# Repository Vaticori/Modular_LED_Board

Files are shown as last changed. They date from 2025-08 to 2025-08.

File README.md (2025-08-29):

# Modular LED Board TMR
Modular PCB to supply power to and control LED strips, providing input for both 5V and 12V. For the Mars Rover of the Toronto Metropolitan Robotics Team

# [View Interactive 3D Model of my PCB!](https://skfb.ly/pACWx)
 
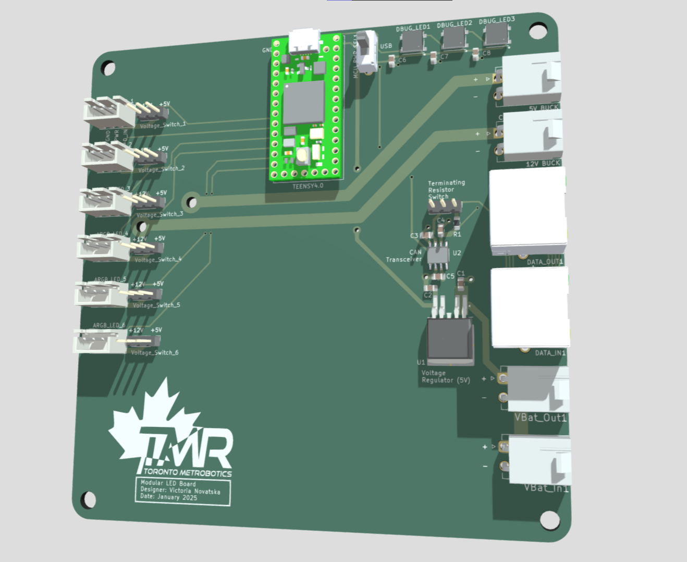
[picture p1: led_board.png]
Led Board


## Schematic 
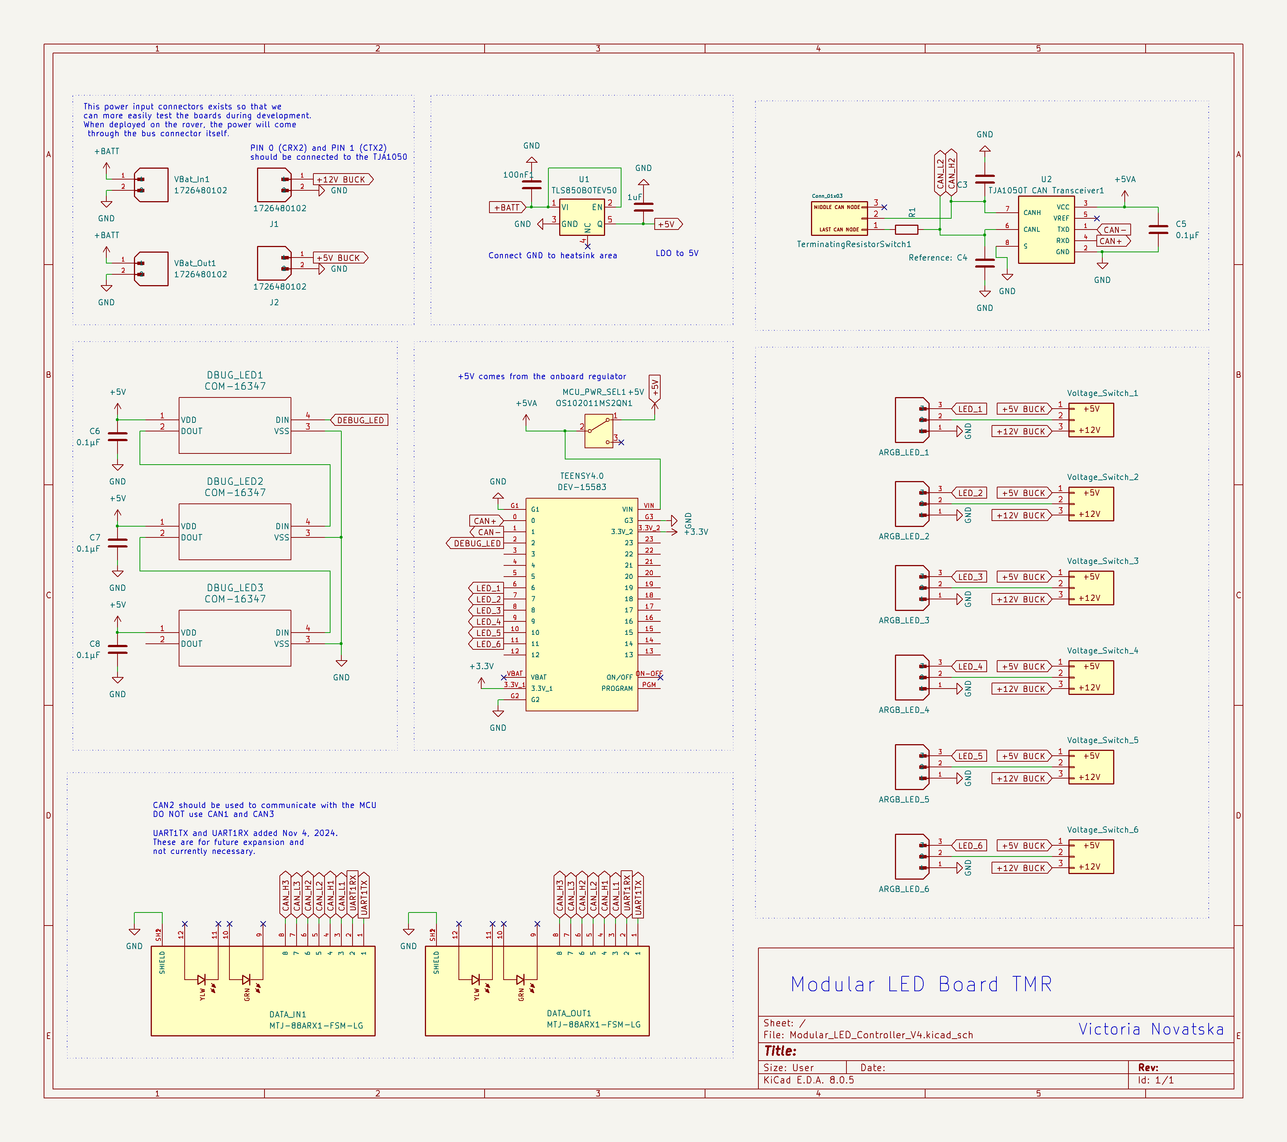
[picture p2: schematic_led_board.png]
Schematic


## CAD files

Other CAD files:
Modular_LED_Board/TJA1050T_CM_118.step

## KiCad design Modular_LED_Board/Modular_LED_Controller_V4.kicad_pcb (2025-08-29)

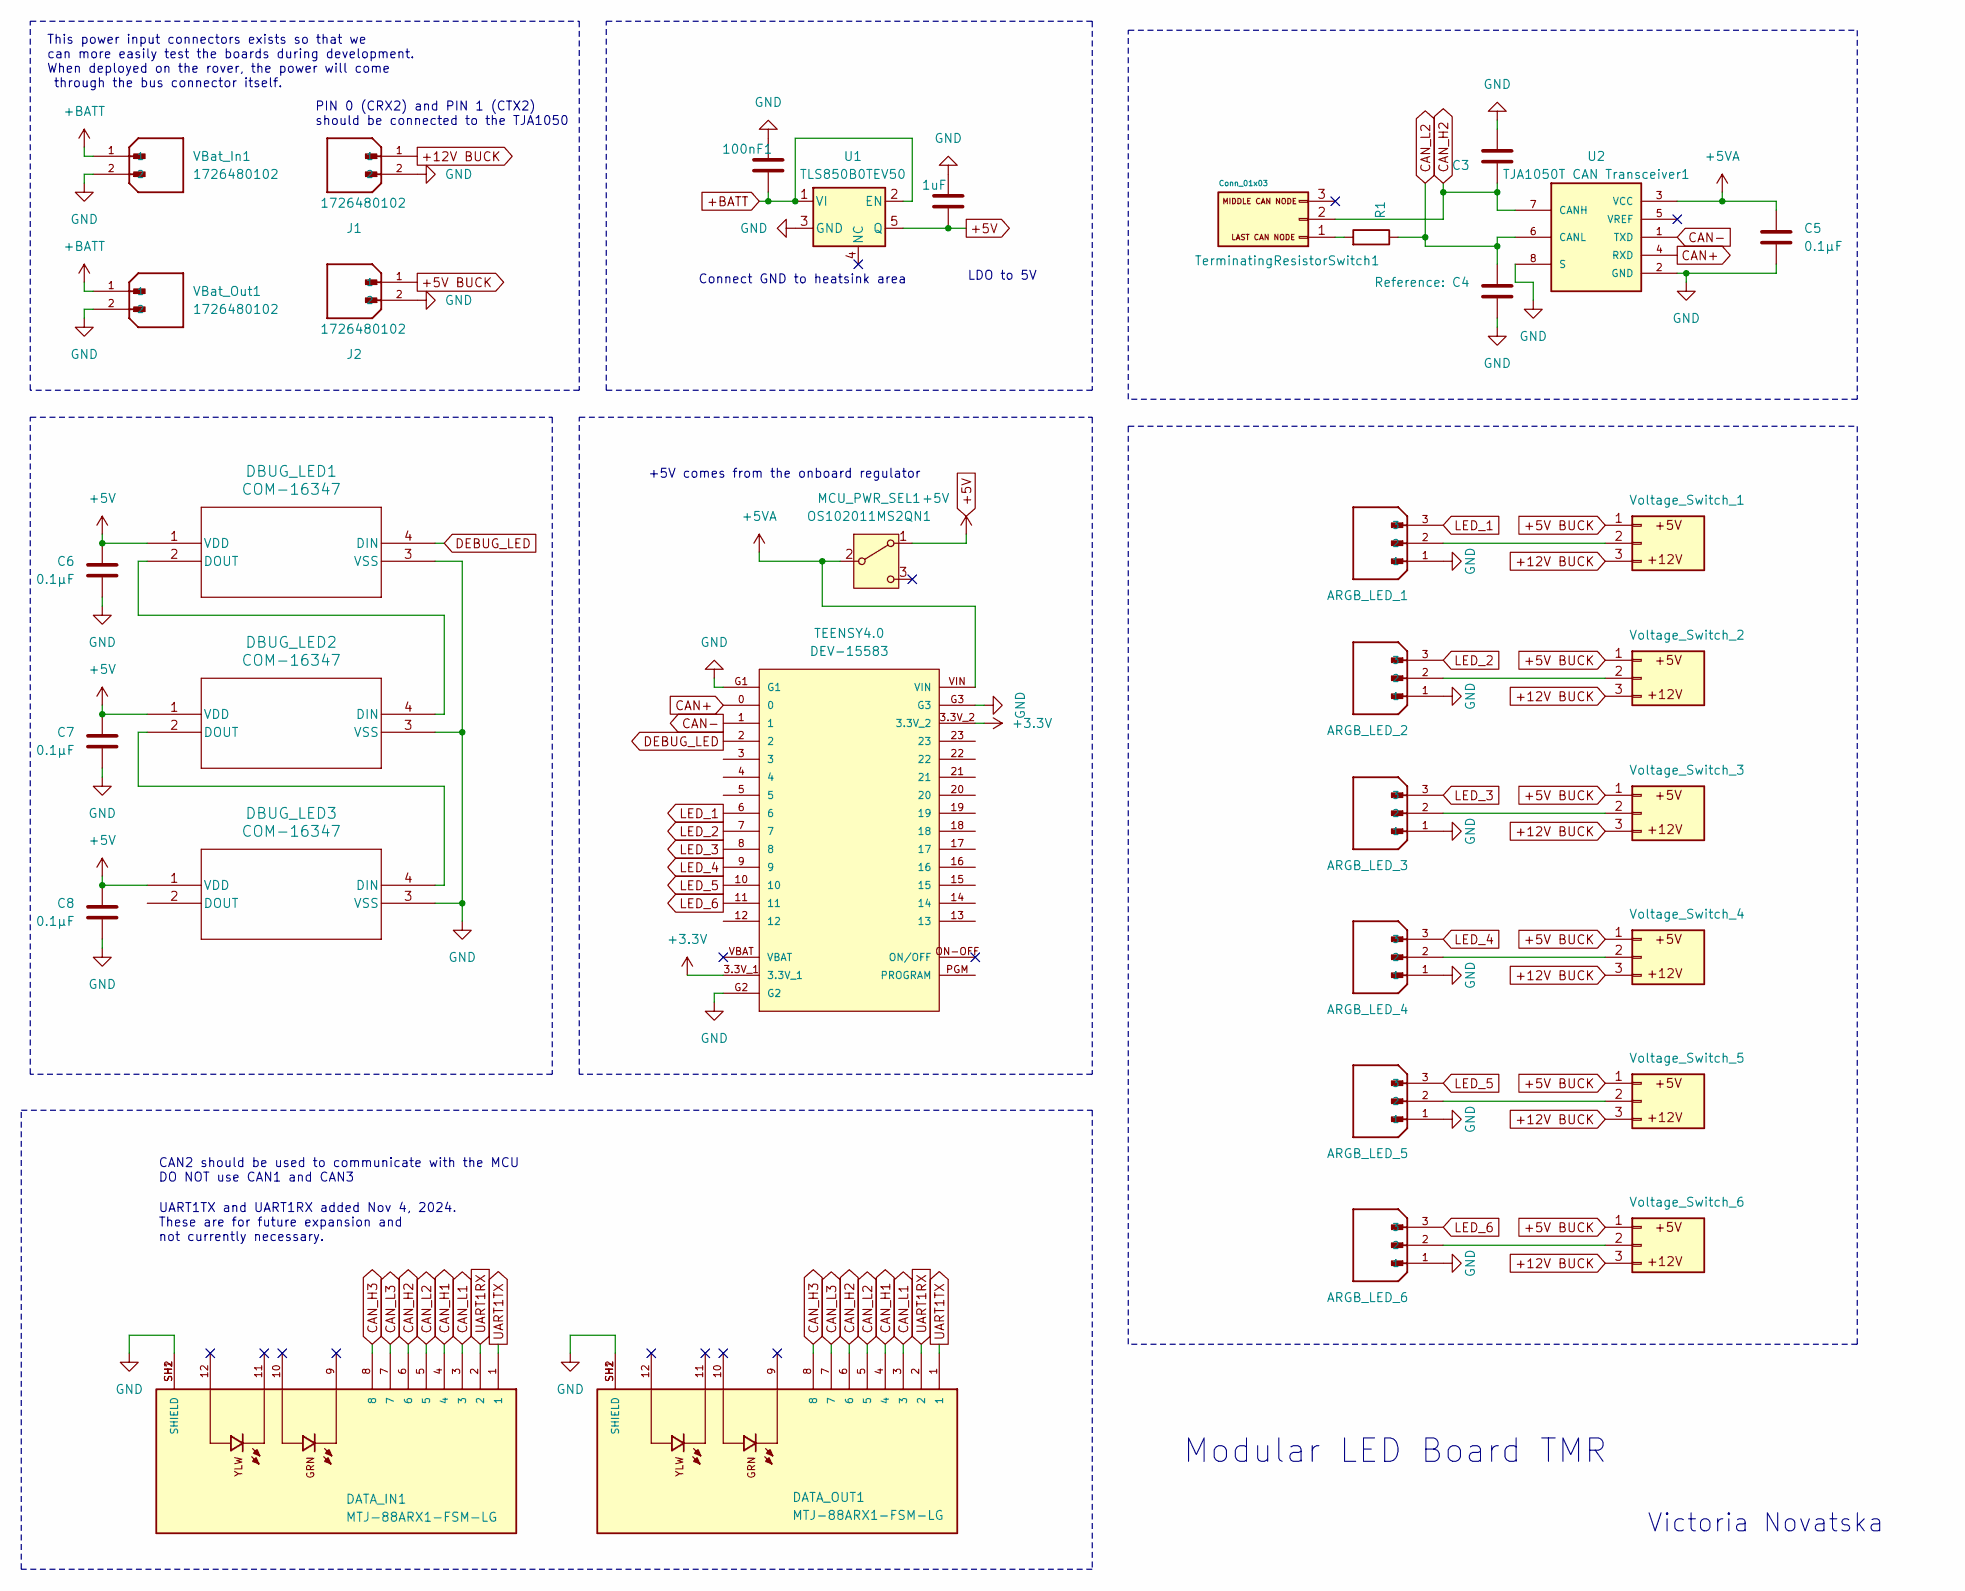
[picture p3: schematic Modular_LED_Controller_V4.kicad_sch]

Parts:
ARGB_LED_1, ARGB_LED_2, ARGB_LED_3, ARGB_LED_4, ARGB_LED_5, ARGB_LED_6: B3B-XH-A(LF)(SN); JST_XH_B3B-XH-A_1x03_P2.50mm_Vertical
C1: 100nF1; C_0805_2012Metric_Pad1.18x1.45mm_HandSolder
C2: 1uF; C_0805_2012Metric_Pad1.18x1.45mm_HandSolder
C3: 30pF_1; C_0805_2012Metric_Pad1.18x1.45mm_HandSolder
C4: 30pF; C_0805_2012Metric_Pad1.18x1.45mm_HandSolder
C5, C6, C7, C8: 0.1µF; C_0805_2012Metric_Pad1.18x1.45mm_HandSolder
DATA_IN1: MTJ-88ARX1-FSM-LG; ADAMTECH_MTJ-88ARX1-FSM-LG
DATA_OUT1: MTJ-88ARX1-FSM-LG; ADAMTECH_MTJ-88ARX1-FSM-LG
DBUG_LED1, DBUG_LED2, DBUG_LED3: COM-16347; COM-16347_SPK-M
J1, J2: 1726480102; MOLEX_1726480102; PARTREV A2
MCU_PWR_SEL1: OS102011MS2QN1
R1: 120Ω; R_0805_2012Metric_Pad1.20x1.40mm_HandSolder
TEENSY4.0: DEV-15583; MODULE_DEV-15583
TerminatingResistorSwitch1: Conn_01x03; PinHeader_1x03_P2.54mm_Vertical
U1: TLS850B0TEV50; TO-252-4
U2: TJA1050T CAN Transceiver1; SOT96-1
VBat_In1: 1726480102; MOLEX_1726480102
VBat_Out1: 1726480102; MOLEX_1726480102
Voltage_Switch_1, Voltage_Switch_2, Voltage_Switch_3, Voltage_Switch_4, Voltage_Switch_5, Voltage_Switch_6: PinHeader_1x03_P2.54mm_Vertical

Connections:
+3.3V: TEENSY4.0.3.3V_1, TEENSY4.0.3.3V_2
+5V: C2.1, C6.1, C7.1, C8.1, DBUG_LED1.1 (VDD), DBUG_LED2.1 (VDD), DBUG_LED3.1 (VDD), MCU_PWR_SEL1.1 (A), U1.5 (Q)
+5V BUCK: J2.1, Voltage_Switch_1.1, Voltage_Switch_2.1, Voltage_Switch_3.1, Voltage_Switch_4.1, Voltage_Switch_5.1, Voltage_Switch_6.1
+5VA: C5.1, MCU_PWR_SEL1.2 (B), TEENSY4.0.VIN, U2.3 (VCC)
+12V BUCK: J1.1, Voltage_Switch_1.3, Voltage_Switch_2.3, Voltage_Switch_3.3, Voltage_Switch_4.3, Voltage_Switch_5.3, Voltage_Switch_6.3
+BATT: C1.1, U1.1 (VI), U1.2 (EN), VBat_In1.1, VBat_Out1.1
CAN+: TEENSY4.0.0, U2.4 (RXD)
CAN-: TEENSY4.0.1, U2.1 (TXD)
CAN_H1: DATA_IN1.4, DATA_OUT1.4
CAN_H2: C3.1, DATA_IN1.6, DATA_OUT1.6, TerminatingResistorSwitch1.2, U2.7 (CANH)
CAN_H3: DATA_IN1.8, DATA_OUT1.8
CAN_L1: DATA_IN1.3, DATA_OUT1.3
CAN_L2: C4.1, DATA_IN1.5, DATA_OUT1.5, R1.1, U2.6 (CANL)
CAN_L3: DATA_IN1.7, DATA_OUT1.7
DEBUG_LED: DBUG_LED1.4 (DIN), TEENSY4.0.2
GND: ARGB_LED_1.1, ARGB_LED_2.1, ARGB_LED_3.1, ARGB_LED_4.1, ARGB_LED_5.1, ARGB_LED_6.1, C1.2, C2.2, C3.2, C4.2, C5.2, C6.2, C7.2, C8.2, DATA_IN1.SH1 (SHIELD), DATA_IN1.SH2 (SHIELD), DATA_OUT1.SH1 (SHIELD), DATA_OUT1.SH2 (SHIELD), DBUG_LED1.3 (VSS), DBUG_LED2.3 (VSS), DBUG_LED3.3 (VSS), J1.2, J2.2, TEENSY4.0.G1, TEENSY4.0.G2, TEENSY4.0.G3, U1.3 (GND), U2.2 (GND), U2.8 (S), VBat_In1.2, VBat_Out1.2
LED_1: ARGB_LED_1.3, TEENSY4.0.6
LED_2: ARGB_LED_2.3, TEENSY4.0.7
LED_3: ARGB_LED_3.3, TEENSY4.0.8
LED_4: ARGB_LED_4.3, TEENSY4.0.9
LED_5: ARGB_LED_5.3, TEENSY4.0.10
LED_6: ARGB_LED_6.3, TEENSY4.0.11
unnamed: DBUG_LED1.2 (DOUT), DBUG_LED2.4 (DIN)
unnamed: DBUG_LED2.2 (DOUT), DBUG_LED3.4 (DIN)
unnamed: R1.2, TerminatingResistorSwitch1.1
unnamed: ARGB_LED_1.2, Voltage_Switch_1.2
unnamed: ARGB_LED_2.2, Voltage_Switch_2.2
unnamed: ARGB_LED_3.2, Voltage_Switch_3.2
unnamed: ARGB_LED_4.2, Voltage_Switch_4.2
unnamed: ARGB_LED_5.2, Voltage_Switch_5.2
unnamed: ARGB_LED_6.2, Voltage_Switch_6.2
UART1RX: DATA_IN1.2, DATA_OUT1.2
UART1TX: DATA_IN1.1, DATA_OUT1.1

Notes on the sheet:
+5V comes from the onboard regulator
CAN2 should be used to communicate with the MCU DO NOT use CAN1 and CAN3
This power input connectors exists so that we can more easily test the boards during development. When deployed on the rover, the power will come through the bus connector itself.
Victoria Novatska
PIN 0 (CRX2) and PIN 1 (CTX2) should be connected to the TJA1050
LDO to 5V
Modular LED Board TMR
Connect GND to heatsink area
UART1TX and UART1RX added Nov 4, 2024. These are for future expansion and not currently necessary.

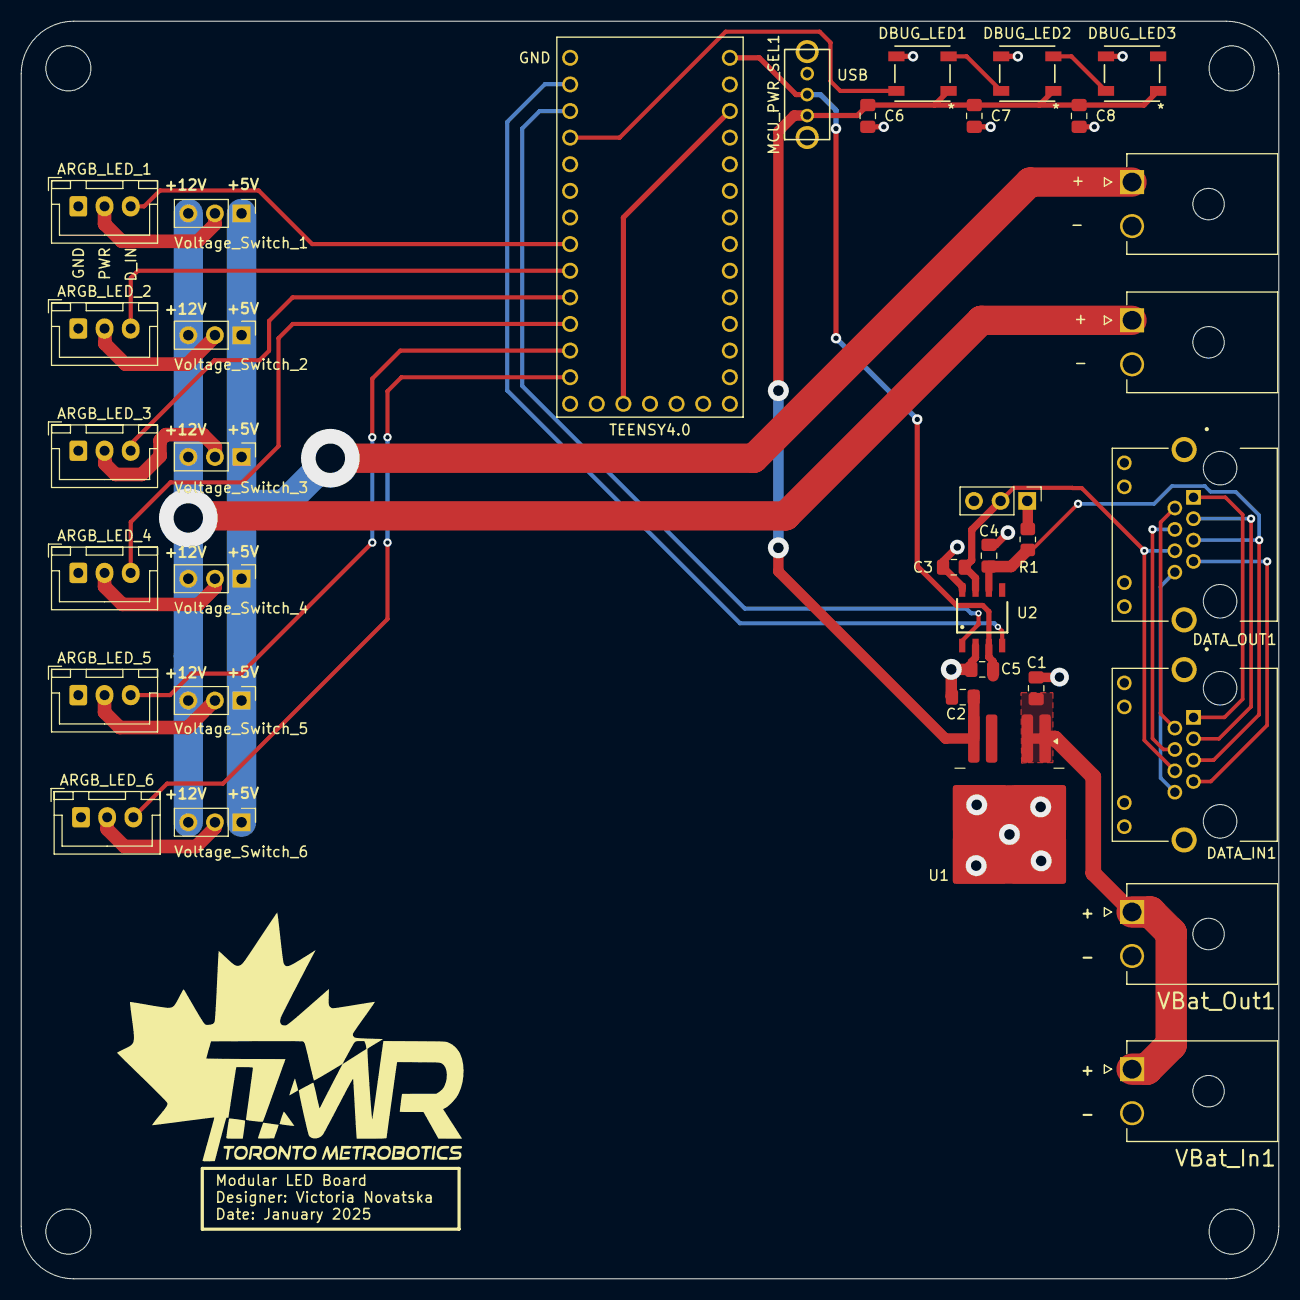
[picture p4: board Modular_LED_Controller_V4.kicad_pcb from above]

Board: 2 copper layers, 120.0 x 120.0 mm, 35 parts (0 on the bottom side), 33 nets.
